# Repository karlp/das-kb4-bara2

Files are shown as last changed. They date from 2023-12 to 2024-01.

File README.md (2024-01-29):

## Das Keyboard 4 controller replacement - usb2 only.

I had a mains accident with my [das keyboard](https://www.daskeyboard.com/daskeyboard-4-professional/), and blew out the USB3 hub, the Via xxxxfixmexx part.  
I sourced a replacement, but it never came up, so perhaps it was more broken.

Today, I've had the idea of just making a replacement controller board for it.  They _keys_ are presumably all still fine.

So... Pick a cheap in stock MCU supported by [QMK](https://qmk.fm/), just go for a plain USB2-HS hub part, and.. profit?

## Status
[Have a working version](h2/r2023-12), though the layout was somewhat poorly thought out. It's not as cheap in assembly and manufacturing as the rest of the design might imply.

## TODO
 * Make a cheaper version, with better mechanical fit.
 * apply for a OSHW number?)

## License
Consider this "open hardware"

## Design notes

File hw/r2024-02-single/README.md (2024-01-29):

## What's it like?

## Status

initial stages only

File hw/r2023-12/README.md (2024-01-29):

## What's it like?
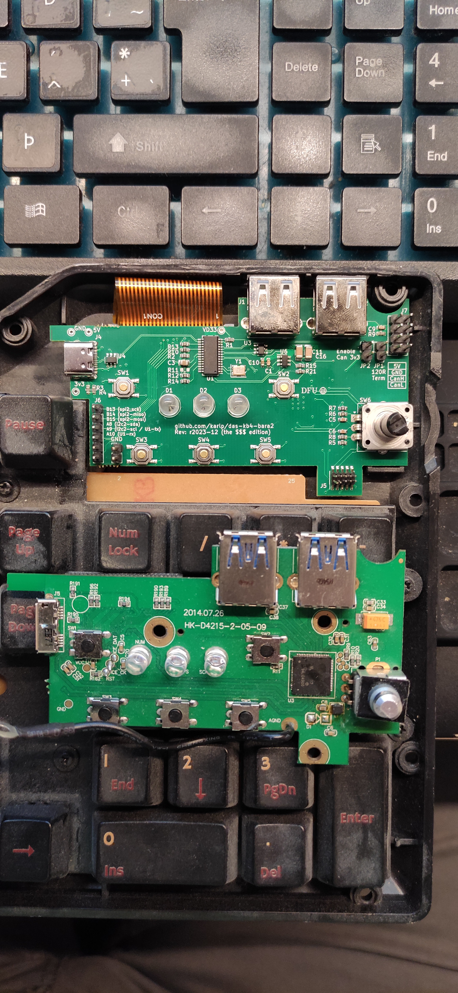
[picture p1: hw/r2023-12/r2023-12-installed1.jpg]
installed side by side


## Firmware
[My own QMK fork has the single patch needed for this revision](https://github.com/karlp/qmk_firmware/releases/tag/r2023_12-v1.0).  I'm not (currently) planning on submitting this to QMK, as this hardware revision has some issues.

The firmware works perfectly well though.

## Don't use this one
I was badly misled that jlc could do double sided assembly for "no" extra price, so I didn't take any real care with it.

It wouldn't realllly be hard to make this a single sided assembly board, but, damnit, I didn't have time to go and do it all again,
so I just decided to bite the bullet and get rev1 back.  This ended up costing ~160 for 5 boards, plus shipping and taxes. (5 pcbs is ~$10 and 5 boards worth of parts s ~$28)

If it all works out, and I'm still crazy, I may make a rev2 of this, that simplifies this better, and uses single sided assembly to make it massively cheaper to have assembled.  I don't _really_ enjoy stencilling and soldering at home...

This also means I get 5 boards, completely assembled with alllll optional bits.  (It won't fit in the keyboard like that, but... whatever, we can work with that later)

## Actual errors/fixes required
there are couple of NPTH holes on the original board that I missed were important for mounting the button/led frame.
Likewise, a couple of landing spaces for that frame that now have parts in them.
Not huge, but definitely need to be done to move it forwards as far as a "replacement" goes.

Also, the ribbon cable mount needs to move left maybe 5mm, to avoid bending it unnecessarily.

Finally, the USB-C connector shoudl move about 3.5mm down to fit cables better in the keyboard.

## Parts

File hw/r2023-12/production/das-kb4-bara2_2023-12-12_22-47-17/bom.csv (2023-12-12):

Designator | Footprint | Quantity | Value | LCSC Part #
C1, C15, C2, C4, C7, C9 | 0603 | 6 | 100nF | C14663
C10, C12, C13, C14, C8 | 0603 | 5 | 1uF | C15849
C11, C16 | 1206 | 2 | 100uF | C15008
C3 | 0805 | 1 | 10uF | C15850
C5, C6 | 0603 | 2 | 10nF | C57112
D1 | LED_D5.0mm | 1 | NUM_LOCK | C125756
D2 | LED_D5.0mm | 1 | CAPS_LOCK | C125756
D3 | LED_D5.0mm | 1 | SCROLL_LOCK | C125756
D4 | SOT-23 | 1 | NUP2105L | C5261087
J1, J2 | USB_A_Stewart_SS-52100-001_Horizontal | 2 | USB_A | C42643
J3 | TE_2-84952-6_1x26-1MP_P1.0mm_Horizontal | 1 | Conn_01x26_Socket | C262356
J4 | USB_C_Receptacle_G-Switch_GT-USB-7010ASV | 1 | USB_C_Receptacle_USB2.0 | C2927038
J5 | PinHeader_2x05_P1.27mm_Vertical_SMD | 1 | Conn_ARM_JTAG_SWD_10 | C6332249
J6 | PinHeader_1x06_P2.54mm_Vertical | 1 | Conn_01x06_Socket
J7 | PinHeader_2x04_P2.54mm_Vertical | 1 | Conn_02x04_Odd_Even
JP1, JP2 | PinHeader_1x02_P2.54mm_Vertical | 2 | Jumper_2_Open
JP3 | PinHeader_1x02_P2.54mm_Vertical | 1 | GND
R1 | 0603 | 1 | 2k7/1% | C13167
R10 | 0603 | 1 | 0 | C21189
R12, R13, R14, R15, R19, R2, R21, R5, R6, R7, R8 | 0603 | 11 | 10k | C25804
R16, R17, R18, R9 | 0603 | 4 | 220 | C22962
R20 | 0603 | 1 | 120 | C22787
R3, R4 | 0603 | 2 | 5k1 | C23186
SW1 | SW_SPST_TL3342 | 1 | PWR | C318884
SW2 | SW_SPST_TL3342 | 1 | MUTE | C318884
SW3 | SW_SPST_TL3342 | 1 | PREV | C318884
SW4 | SW_SPST_TL3342 | 1 | PLAY_PAUSE | C318884
SW5 | SW_SPST_TL3342 | 1 | NEXT | C318884
SW6 | RotaryEncoder_Alps_EC12E_Vertical_H20mm_CircularMountingHoles | 1 | Volume | C470597
U1 | SSOP-28_3.9x9.9mm_P0.635mm | 1 | FE1.1s | C6706491
U2 | QFN-48-1EP_7x7mm_P0.5mm_EP5.6x5.6mm | 1 | STM32G431CBUx | C529356
U3, U4 | SOT-23-6 | 2 | SRV05-4 | C7420376
U5 | SOT-23-3 | 1 | XC6206PxxxMR | C5446
U6 | SOT-23-6 | 1 | AP2552W6 | C441824
U7 | SOIC-8_3.9x4.9mm_P1.27mm | 1 | SN65HVD230 | C12084
Y1 | Crystal_SMD_3225-4Pin_3.2x2.5mm | 1 | 12MHz | C9002

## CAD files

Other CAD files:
board_outline1.FCStd

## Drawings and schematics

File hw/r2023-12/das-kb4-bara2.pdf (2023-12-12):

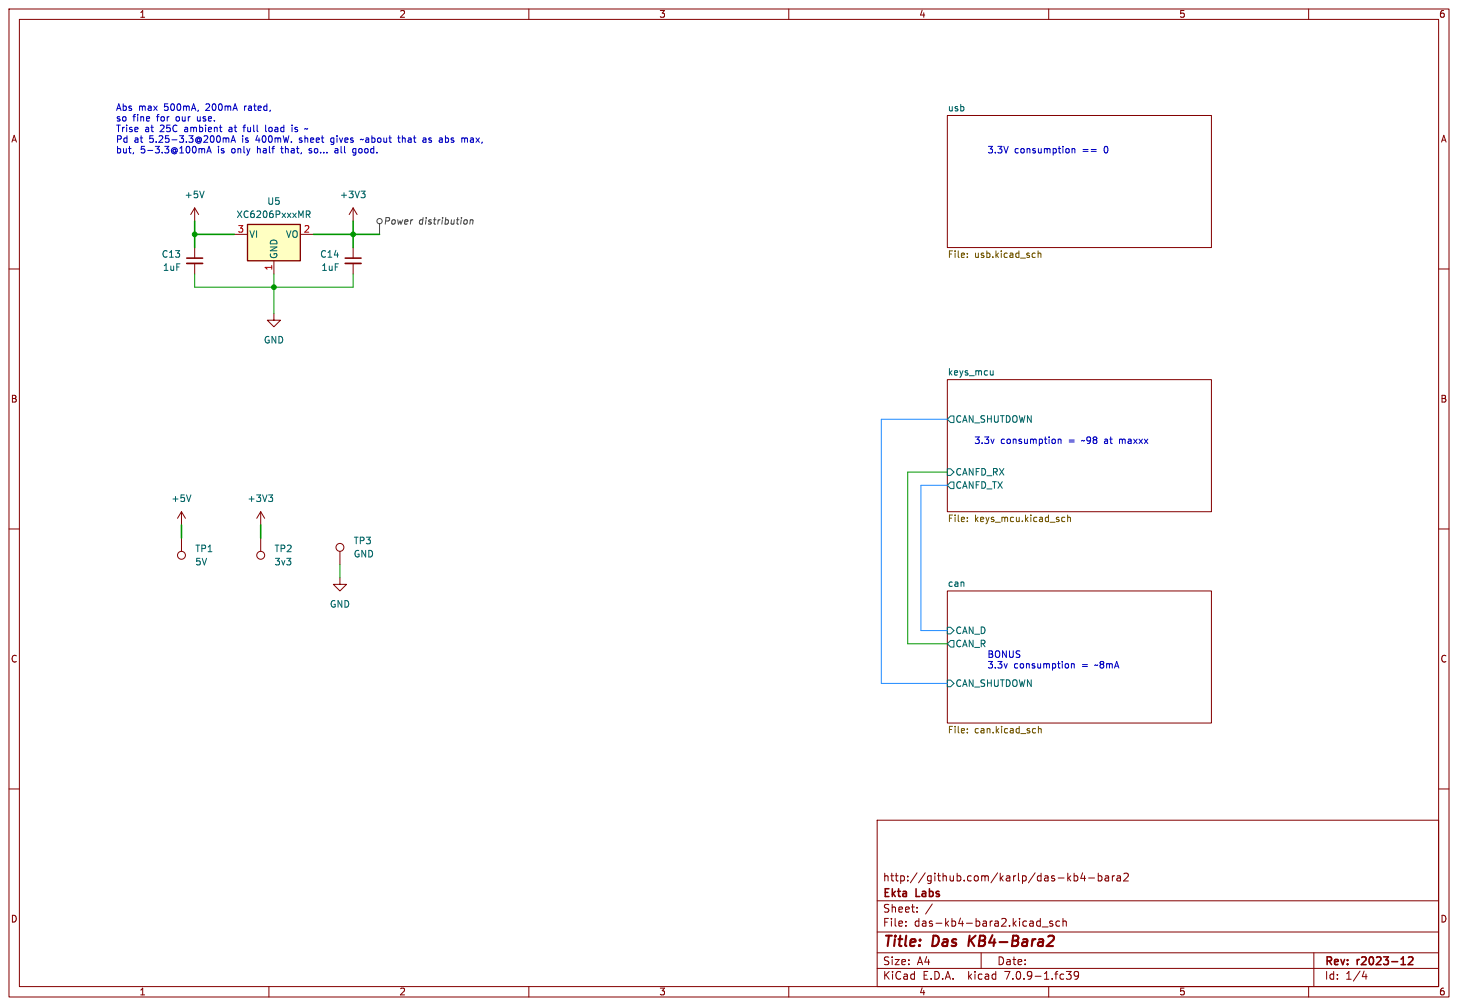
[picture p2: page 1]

http://github.com/karlp/das-kb4-bara2 CAN_D

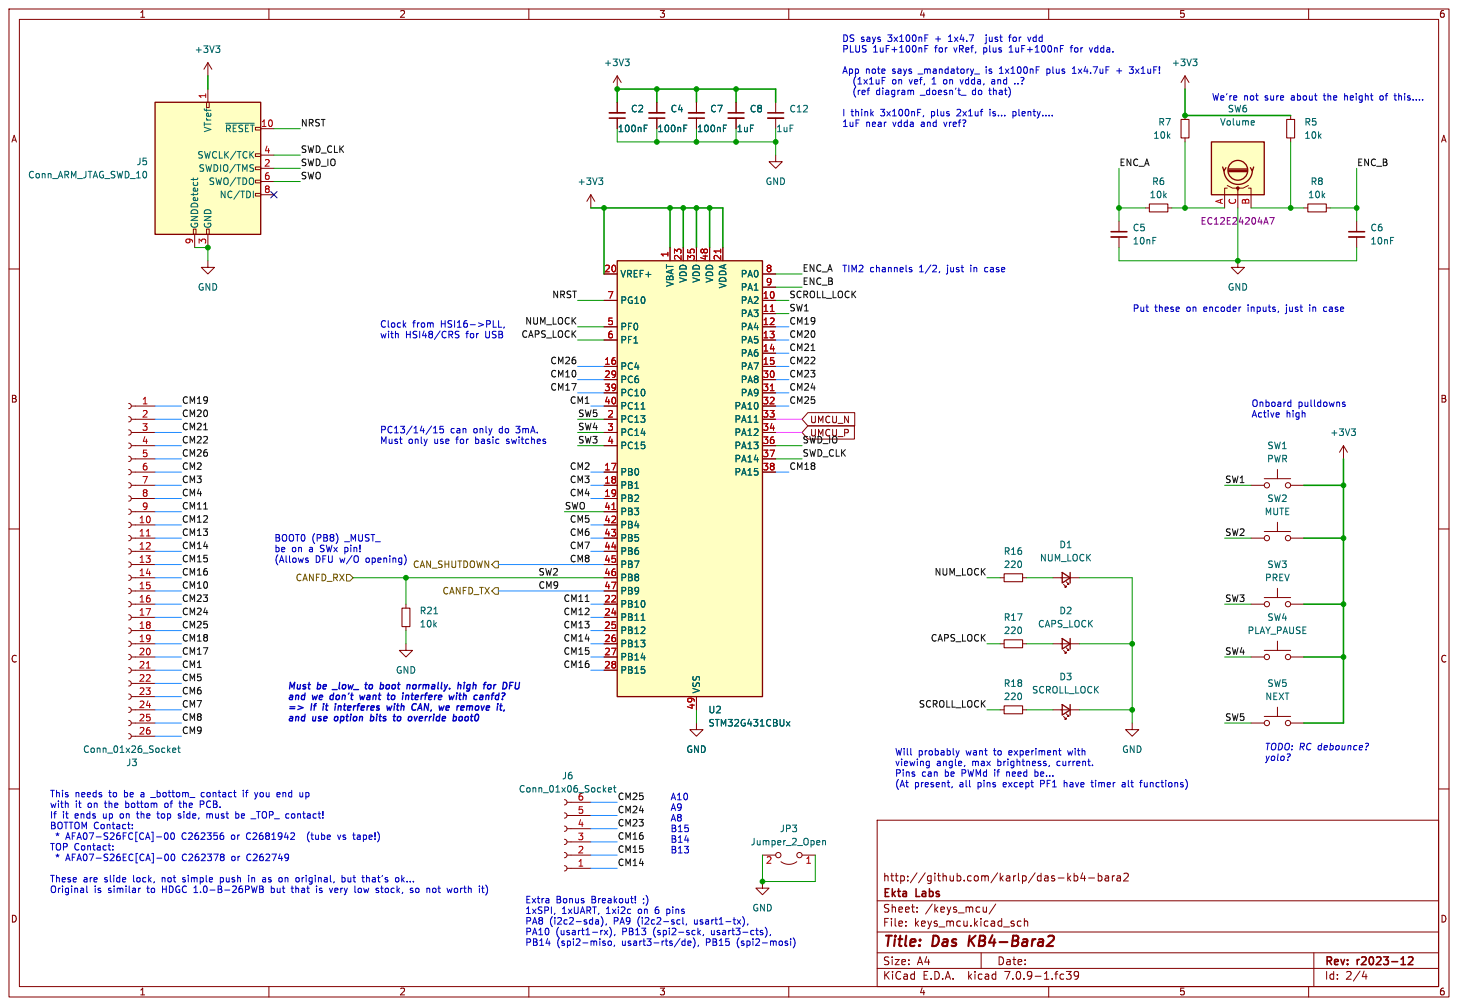
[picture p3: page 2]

We're not sure about the height of this.... U2STM32G431CBUx VBAT

(ref diagram _doesn't_ do that)

1 PA2 10 PA3 11 PA4 12 PA5 13 PA6 14 PA7 15 PC4 16 PB0 17 PB1 18 PB2 19 PC13 2 VREF+ 20 VDDA 21 PB10 22 VDD 23 PB11 24 PB12 25 PB13 26 PB14 27 PB15 28 PC6 29 PC14 3 PA8 30 PA9 31 PA10 32 PA11 33 PA12 34 VDD 35 PA13 36 PA14 37 PA15 38 PC10 39 PC15 4 PC11 40 PB3 41 PB4 42 PB5 43 PB6 44 PB7 45 PB8 46 PB9 47 VDD 48 VSS 49 PF0 5 PF1 6 PG10 7 PA0 8 PA1 9 C2
100nF GND

3 SWCLK/TCK 4 SWO/TDO 6 NC/TDI 8 GNDDetect 9

1 PA2 10 PA3 11 PA4 12 PA5 13 PA6 14 PA7 15 PC4 16 PB0 17 PB1 18 PB2 19 PC13 2 VREF+ 20 VDDA 21 PB10 22 VDD 23 PB11 24 PB12 25 PB13 26 PB14 27 PB15 28 PC6 29 PC14 3 PA8 30 PA9 31 PA10 32 PA11 33 PA12 34 VDD 35 PA13 36 PA14 37 PA15 38 PC10 39 PC15 4 PC11 40 PB3 41 PB4 42 PB5 43 PB6 44 PB7 45 PB8 46 PB9 47 VDD 48 VSS 49 PF0 5 PF1 6 PG10 7 PA0 8 PA1 9 U2STM32G431CBUx CAN_SHUTDOWN

Put these on encoder inputs, just in case Must be _low_ to boot normally. high for DFU

be on a SWx pin!
(Allows DFU w/O opening)

and we don't want to interfere with canfd?

http://github.com/karlp/das-kb4-bara2

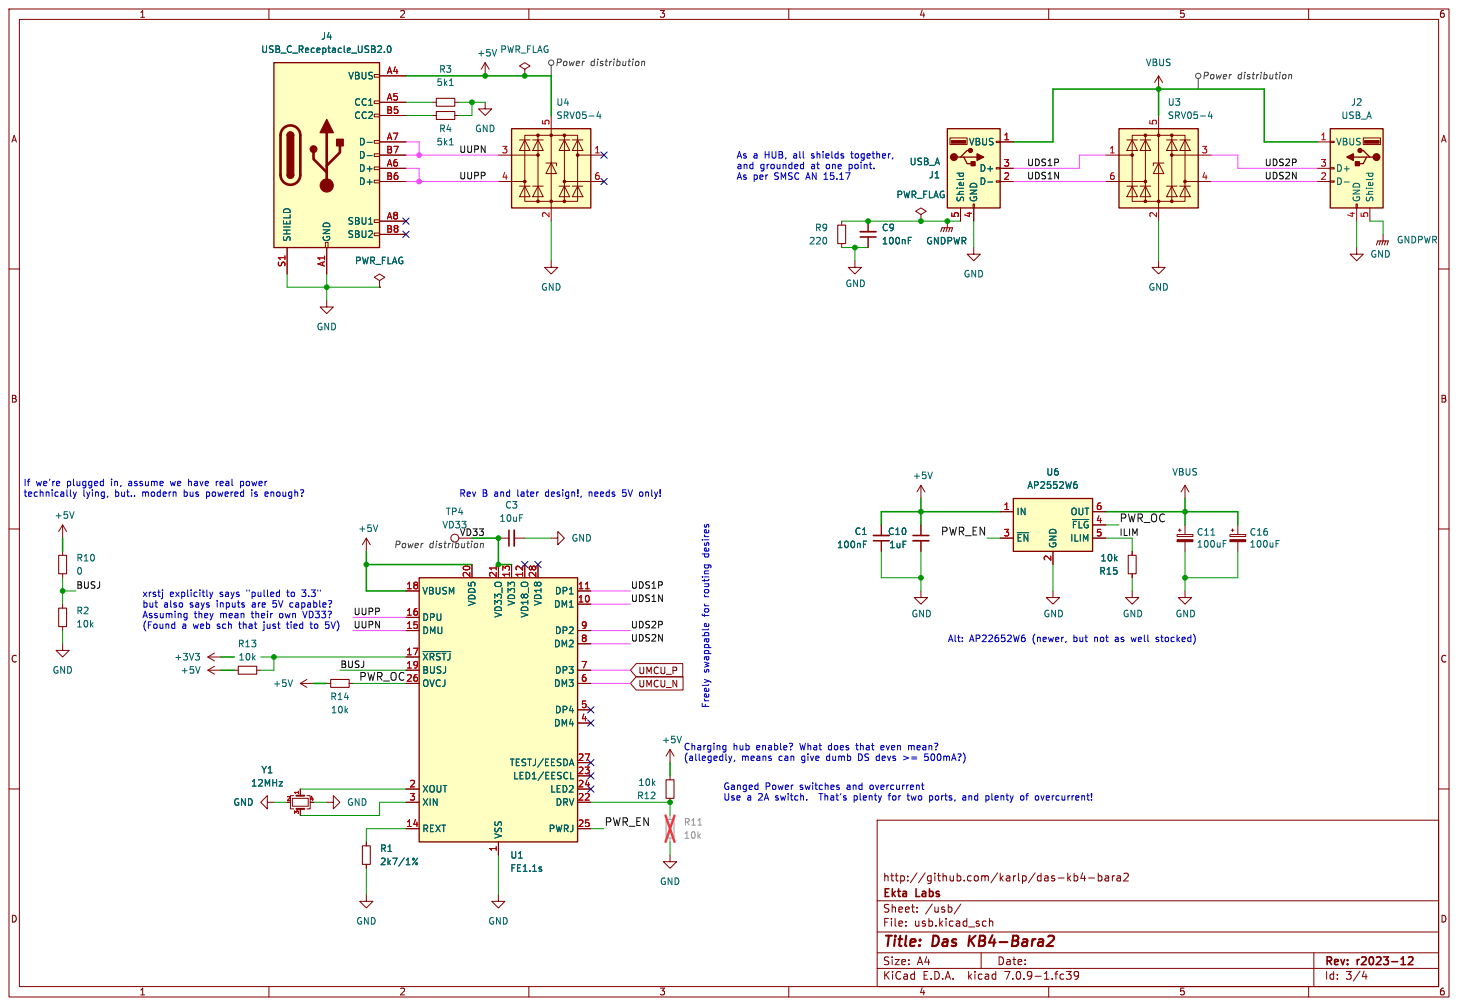
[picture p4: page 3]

Power distribution Power distribution UMCU_P UMCU_N

If we're plugged in, assume we have real power

1 DM1 10 DP1 11 VD18_O 12 VD33 13 REXT 14 DMU 15 DPU 16 ~{XRSTJ} 17 VBUSM 18 BUSJ 19 XOUT 2 VDD5 20 VD33_O 21 DRV 22

Assuming they mean their own VD33?

http://github.com/karlp/das-kb4-bara2

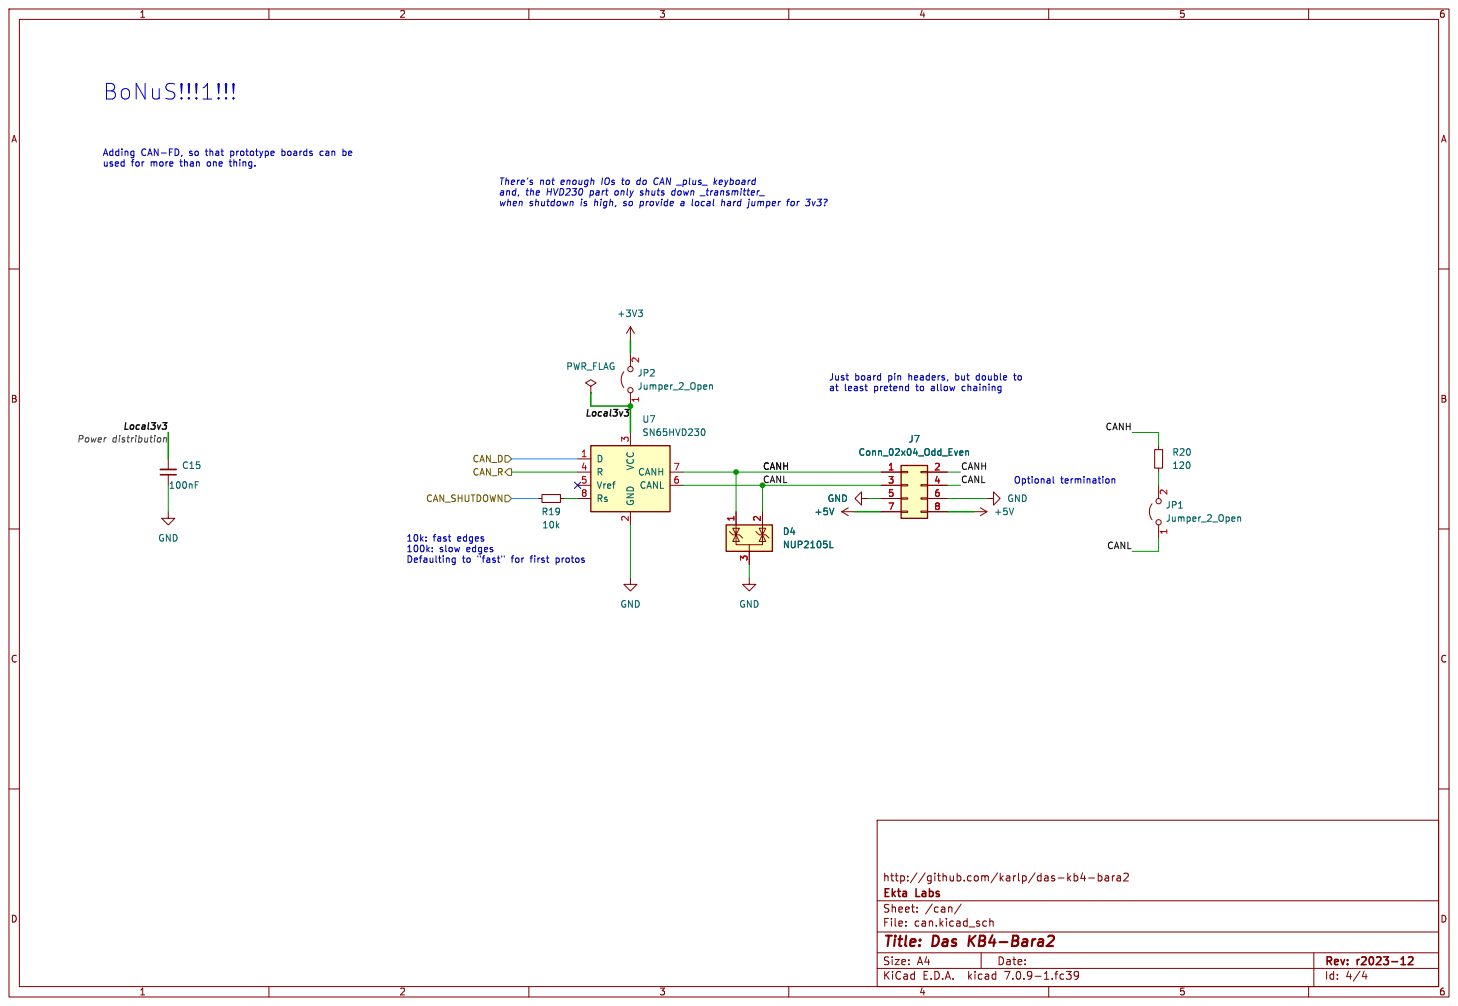
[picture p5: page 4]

used for more than one thing.

and, the HVD230 part only shuts down _transmitter_ when shutdown is high, so provide a local hard jumper for 3v3? D4 NUP2105L

Just board pin headers, but double to
at least pretend to allow chaining

10k: fast edges 100k: slow edges

http://github.com/karlp/das-kb4-bara2

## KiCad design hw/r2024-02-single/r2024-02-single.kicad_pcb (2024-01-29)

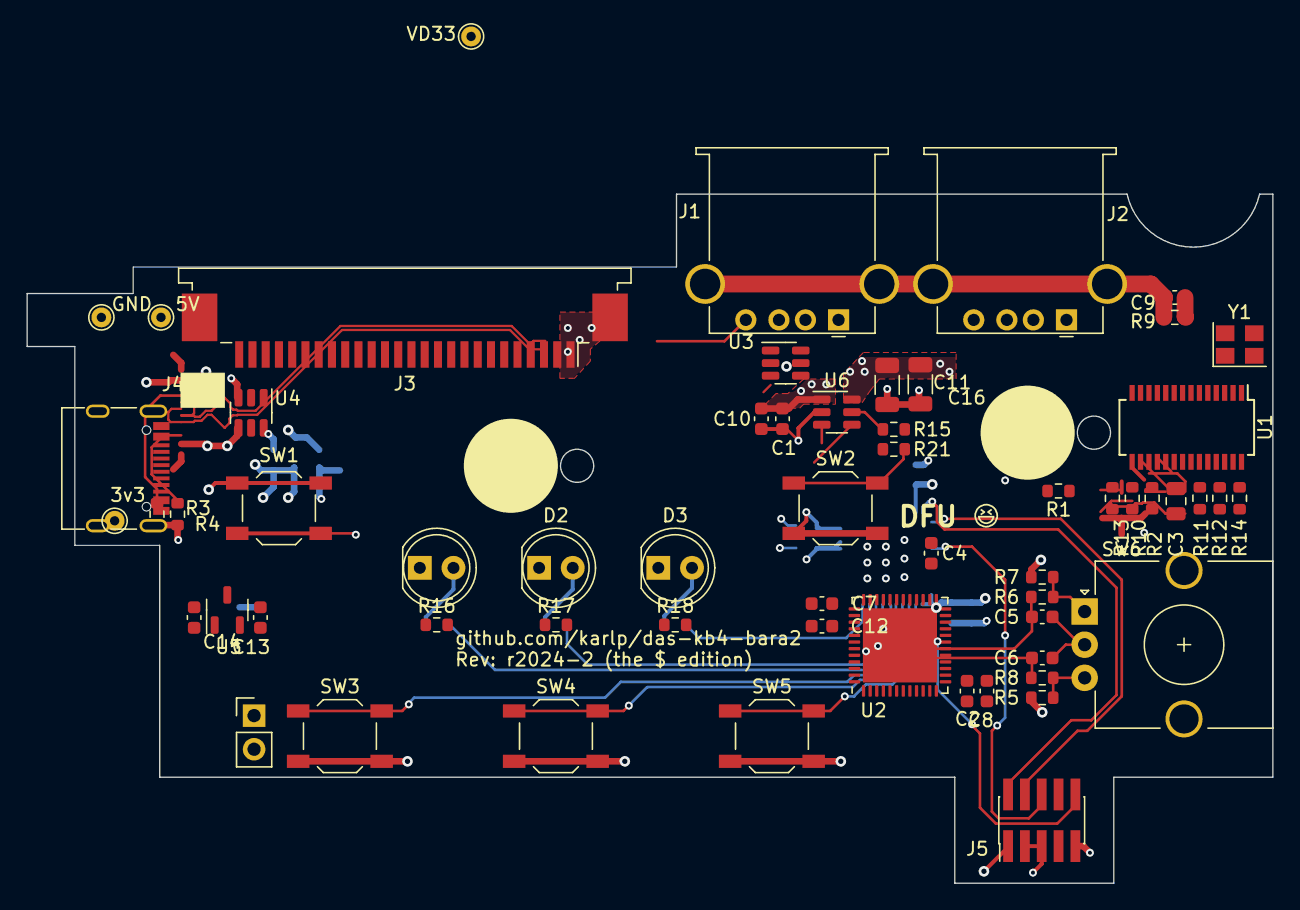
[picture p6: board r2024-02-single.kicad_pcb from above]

Board: 4 copper layers, 94.0 x 52.0 mm, 60 parts (0 on the bottom side), 69 nets.

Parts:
C1, C2, C4, C7, C9: 100nF; C_0603_1608Metric
C3: 10uF; C_0805_2012Metric
C5, C6: 10nF; C_0603_1608Metric
C8, C10, C12, C13, C14: 1uF; C_0603_1608Metric
C11, C16: 100uF; C_1206_3216Metric
D1: NUM_LOCK; LED_D5.0mm
D2: CAPS_LOCK; LED_D5.0mm
D3: SCROLL_LOCK; LED_D5.0mm
J1, J2: USB_A; USB_A_Stewart_SS-52100-001_Horizontal
J3: Conn_01x26_Socket; TE_2-84952-6_1x26-1MP_P1.0mm_Horizontal
J4: USB_C_Receptacle_USB2.0; USB_C_Receptacle_G-Switch_GT-USB-7010ASV
J5: Conn_ARM_JTAG_SWD_10; PinHeader_2x05_P1.27mm_Vertical_SMD
JP3: Jumper_2_Open; PinHeader_1x02_P2.54mm_Vertical
R1: 2k7/1%; R_0603_1608Metric
R2, R5, R6, R7, R8, R11, R12, R13, R14, R15, R21: 10k; R_0603_1608Metric
R3, R4: 5k1; R_0603_1608Metric
R9, R16, R17, R18: 220; R_0603_1608Metric
R10: 0; R_0603_1608Metric
SW1: PWR; SW_SPST_TL3342
SW2: MUTE; SW_SPST_TL3342
SW3: PREV; SW_SPST_TL3342
SW4: PLAY_PAUSE; SW_SPST_TL3342
SW5: NEXT; SW_SPST_TL3342
SW6: Volume; RotaryEncoder_Alps_EC12E_Vertical_H20mm_CircularMountingHol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
TP1: 5V; TestPoint_THTPad_D1.5mm_Drill0.7mm
TP2: 3v3; TestPoint_THTPad_D1.5mm_Drill0.7mm
TP3: GND; TestPoint_THTPad_D1.5mm_Drill0.7mm
TP4: VD33; TestPoint_THTPad_D1.5mm_Drill0.7mm
U1: FE1.1s; SSOP-28_3.9x9.9mm_P0.635mm
U2: STM32G431CBUx; QFN-48-1EP_7x7mm_P0.5mm_EP5.6x5.6mm
U3, U4: SRV05-4; SOT-23-6
U5: XC6206PxxxMR; SOT-23-3
U6: AP2552W6; SOT-23-6
Y1: 12MHz; Crystal_SMD_3225-4Pin_3.2x2.5mm

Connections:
+3V3: C2.2, C4.2, C7.2, C8.1, C12.1, C14.1, J5.1 (VTref), R5.1, R7.1, SW1.2, SW2.2, SW3.2, SW4.2, SW5.2, TP2.1, U2.1 (VBAT), U2.20 (VREF+), U2.21 (VDDA), U2.23 (VDD), U2.35 (VDD), U2.48 (VDD), U5.2 (VO)
+5V: C1.2, C10.1, C13.1, J4.A4 (VBUS), J4.A9 (VBUS), J4.B4 (VBUS), J4.B9 (VBUS), R10.1, R12.1, R13.1, R14.1, TP1.1, U1.18 (VBUSM), U1.20 (VDD5), U4.5 (VBUS), U5.3 (VI), U6.1 (IN)
/keys_mcu/CAPS_LOCK: R17.1, U2.6 (PF1)
/keys_mcu/CM1: J3.21, U2.40 (PC11)
/keys_mcu/CM2: J3.6, U2.17 (PB0)
/keys_mcu/CM3: J3.7, U2.18 (PB1)
/keys_mcu/CM4: J3.8, U2.19 (PB2)
/keys_mcu/CM5: J3.22, U2.42 (PB4)
/keys_mcu/CM6: J3.23, U2.43 (PB5)
/keys_mcu/CM7: J3.24, U2.44 (PB6)
/keys_mcu/CM9: J3.26, U2.47 (PB9)
/keys_mcu/CM10: J3.15, U2.29 (PC6)
/keys_mcu/CM11: J3.9, U2.22 (PB10)
/keys_mcu/CM12: J3.10, U2.24 (PB11)
/keys_mcu/CM13: J3.11, U2.25 (PB12)
/keys_mcu/CM14: J3.12, U2.26 (PB13)
/keys_mcu/CM15: J3.13, U2.27 (PB14)
/keys_mcu/CM16: J3.14, U2.28 (PB15)
/keys_mcu/CM17: J3.20, U2.39 (PC10)
/keys_mcu/CM18: J3.19, U2.38 (PA15)
/keys_mcu/CM19: J3.1, U2.12 (PA4)
/keys_mcu/CM20: J3.2, U2.13 (PA5)
/keys_mcu/CM21: J3.3, U2.14 (PA6)
/keys_mcu/CM22: J3.4, U2.15 (PA7)
/keys_mcu/CM23: J3.16, U2.30 (PA8)
/keys_mcu/CM24: J3.17, U2.31 (PA9)
/keys_mcu/CM25: J3.18, U2.32 (PA10)
/keys_mcu/CM26: J3.5, U2.16 (PC4)
/keys_mcu/ENC_A: C5.1, R6.1, U2.8 (PA0)
/keys_mcu/ENC_B: C6.1, R8.2, U2.9 (PA1)
/keys_mcu/NRST: J5.10 (~RESET), U2.7 (PG10)
/keys_mcu/NUM_LOCK: R16.1, U2.5 (PF0)
/keys_mcu/SCROLL_LOCK: R18.1, U2.10 (PA2)
/keys_mcu/SW1: SW1.1, U2.11 (PA3)
/keys_mcu/SW2: R21.2, SW2.1, U2.46 (PB8)
/keys_mcu/SW3: SW3.1, U2.4 (PC15)
/keys_mcu/SW4: SW4.1, U2.3 (PC14)
/keys_mcu/SW5: SW5.1, U2.2 (PC13)
/keys_mcu/SWD_CLK: J5.4 (SWCLK/TCK), U2.37 (PA14)
/keys_mcu/SWD_IO: J5.2 (SWDIO/TMS), U2.36 (PA13)
/keys_mcu/SWO: J5.6 (SWO/TDO), U2.41 (PB3)
/usb/BUSJ: R2.1, R10.2, U1.19 (BUSJ)
/usb/ILIM: R15.1, U6.5 (ILIM)
/usb/PWR_EN: U1.25 (PWRJ), U6.3 (~EN)
/usb/PWR_OC: R14.2, U1.26 (OVCJ), U6.4 (~FLG)
/usb/UDS1N: J1.2 (D-), U1.10 (DM1), U3.6 (I/O4)
/usb/UDS1P: J1.3 (D+), U1.11 (DP1), U3.1 (I/O1)
/usb/UDS2N: J2.2 (D-), U1.8 (DM2), U3.4 (I/O3)
/usb/UDS2P: J2.3 (D+), U1.9 (DP2), U3.3 (I/O2)
/usb/UUPN: J4.A7 (D-), J4.B7 (D-), U1.15 (DMU), U4.3 (I/O2)
/usb/UUPP: J4.A6 (D+), J4.B6 (D+), U1.16 (DPU), U4.4 (I/O3)
/usb/VD33: C3.1, TP4.1, U1.13 (VD33), U1.21 (VD33_O)
GND: C1.1, C2.1, C3.2, C4.1, C5.2, C6.2, C7.1, C8.2, C9.1, C10.2, C11.2, C12.2, C13.2, C14.2, C16.2, D1.1 (K), D2.1 (K), D3.1 (K), J1.4 (GND), J2.4 (GND), J4.A1 (GND), J4.A12 (GND), J4.B1 (GND), J4.B12 (GND), J4.S1 (SHIELD), J5.3 (GND), J5.5 (GND), J5.9 (GNDDetect), JP3.1 (A), JP3.2 (B), R1.2, R2.2, R3.2, R4.2, R9.1, R11.1, R15.2, R21.1, SW6.C, TP3.1, U1.1 (VSS), U2.49 (VSS), U3.2 (GND), U4.2 (GND), U5.1 (GND), U6.2 (GND), Y1.2, Y1.4
GNDPWR: C9.2, J1.5 (Shield), J2.5 (Shield), R9.2
unnamed: D1.2 (A), R16.2
unnamed: D2.2 (A), R17.2
unnamed: D3.2 (A), R18.2
unnamed: J4.A5 (CC1), R3.1
unnamed: J4.B5 (CC2), R4.1
unnamed: R5.2, R8.1, SW6.B
unnamed: R6.2, R7.2, SW6.A
unnamed: R11.2, R12.2, U1.22 (DRV)
unnamed: R1.1, U1.14 (REXT)
unnamed: U1.3 (XIN), Y1.3
unnamed: U1.2 (XOUT), Y1.1
unnamed: R13.2, U1.17 (~XRSTJ)
UMCU_N: U1.6 (DM3), U2.33 (PA11)
UMCU_P: U1.7 (DP3), U2.34 (PA12)
VBUS: C11.1, C16.1, J1.1 (VBUS), J2.1 (VBUS), U3.5 (VBUS), U6.6 (OUT)

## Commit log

2023-11-13 initial joy
    [das-kb4-bara2.kicad_pcb, das-kb4-bara2.kicad_sch, keys_mcu.kicad_sch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]
2023-11-15 sch nearing completion.
    usb side done.
    needs mcu power supply sorting out.
    [das-kb4-bara2.kicad_sch, keys_mcu.kicad_sch, usb.kicad_sch]
2023-11-16 schematic "done" footprints all assigned
    Need working calipers to start getting the board outline and fixed
    positions, but ... mostly there?
    schematic needs "polish" now, more introductions, cleaner text layouts,
    probably more optional test points, throw more caps at it.
    [das-kb4-bara2.kicad_pcb, das-kb4-bara2.kicad_sch, keys_mcu.kicad_sch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]
2023-11-16 initial freecad board outline.
    We didn't include all the switches/leds, and in the end, we allowed
    ourselves more room for the usb-c connector. The original board uses a
    _very_ shallow micro-b3 connector, which leaves no room for the
    power/suspend switch, and there's enough space in the chassis to expand
    in that direction a few mm.
    [board_outline1.FCStd]
2023-11-16 import board outline and lock fixed items
    No routing, just rough placement of all the fixed items.
    [das-kb4-bara2.kicad_pcb, usb.kicad_sch]
2023-11-26 add "bonus" can transceiver ;)
    this is so we can use the round 1 protos for another project...
    also: replace srv05 with an alternate, also jlc preferred, but cheaper
    part. Update power budgets.
    We've done some initial work with the pcb, but we're running into weird
    kicad wx bugs, so we're going to save it all here, and commit, and
    perhaps continue with 7.99.....
    [das-kb4-bara2.kicad_pcb, das-kb4-bara2.kicad_sch, keys_mcu.kicad_sch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]
2023-11-29 routing progress
    Just nice to make some save points every now and again.
    USB seems... ok? Still need to check 3v3 or 5v on the power pullups,
    [das-kb4-bara2.kicad_pcb, das-kb4-bara2.kicad_sch, keys_mcu.kicad_sch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]
2023-11-30 cleanup schematic, break out most of it
    Broke it all out to the right places, now I can go and shuffle all the
    labels to make it line up. Thankfully we can just "freely" route the
    keybaord matrix pins!
    [can.kicad_sch, das-kb4-bara2.kicad_pcb, das-kb4-bara2.kicad_sch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]
2023-12-01 unrouted: 0
    Juggled all the key matrix IOs and reviewed "all" outstanding TODOs
    left: add another cap for downstream Vbus. it's free, and can only
    help.
    left: lots of silk?
    left: place as much free io to pads as can be easily done, for
    test/board reuse.
    [can.kicad_sch, das-kb4-bara2.kicad_pcb, keys_mcu.kicad_sch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]
2023-12-04 shuffled, added bonus, silked up...
    Nearly there..?
    [das-kb4-bara2.kicad_pcb, das-kb4-bara2.kicad_sch, keys_mcu.kicad_sch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]
2023-12-04 fix some erc/drc
    [can.kicad_sch, das-kb4-bara2.kicad_pcb, keys_mcu.kicad_sch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]
2023-12-04 review model for usb a
    [das-kb4-bara2.kicad_pcb]
2023-12-04 move to a lower directory tree
    [can.kicad_sch, das-kb4-bara2.kicad_pcb, das-kb4-bara2.kicad_sch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]
2023-12-05 some pointless irrelevant change after generating gerbers that I can't see
    kicad occasionally does that...
    [das-kb4-bara2.kicad_pcb]
2023-12-12 r2023-12: one last silk update
    We're just going to pay to get a rev done. merry christmas me or
    something. no more faffing about, just get a revision back and stop
    wasting time.
    [das-kb4-bara2.kicad_pcb]
2023-12-12 r2023-12: add more gnd pins
    [das-kb4-bara2.kicad_pcb, das-kb4-bara2.kicad_sch, keys_mcu.kicad_sch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]
2023-12-12 r2023-12: Add production files
    Rotations are still bogus, but whatever. manually cleaned up
    [bom.csv, designators.csv, positions.csv]
2023-12-12 add revision and pdf for posterity
    kicanvas is good, but let's not rely on it
    [can.kicad_sch, das-kb4-bara2.kicad_sch, keys_mcu.kicad_sch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]
2023-12-27 got first r2023-12 back.
    works, dfu shows up. no obvious fuckups then. but see the readme, the
    frame doesn't fit properly.
2023-12-27 r2023-12: add row/column notes
    We got valuable notes from: https://github.com/qmk/qmk_firmware/blob/master/keyboards/handwired/daskeyboard/daskeyboard4/info.json
    We don't have a fully working keyboard yet, but it's nearly there.
    [keys_mcu.kicad_sch]
2024-01-29 r2023_12: add firmware notes and comments on matrix decode
    No intentional changes, just text added while working out the firmware.
    [can.kicad_sch, das-kb4-bara2.kicad_sch, keys_mcu.kicad_sch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]
2024-01-29 r2024-2: initial steps
    Preliminary corrections for physical layout. Added holes, keepouts, and
    moved everything to the right side.
    It's kinda starting all over again isn't it :)
    [keys_mcu.kicad_sch, r2024-02-single.kicad_pcb, r2024-02-single.kicad_sch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]
